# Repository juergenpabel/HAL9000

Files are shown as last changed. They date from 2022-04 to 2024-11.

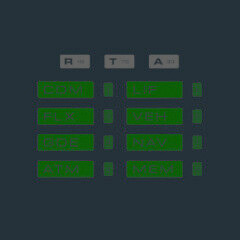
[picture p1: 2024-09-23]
enclosure/services/frontend/resources/images/animations/startup/system-starting/28.jpg

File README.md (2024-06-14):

# HAL9000
Open-source digital voice-assistant in a HAL9000 enclosure.

## Project goals
A digital voice-assistant that is...
1. actually usable (response times, error rates, ...)
2. performs everything on-device ("look ma, no cloud")
3. is entirely Free/Libre Open-Source-Software
4. is as-easy-as-possible to build

Not specifically a goal: price (although somewhat reasonable at 100-200€, depending on selection of components).

## Demos
Some showcase demo videos are published in the wiki: https://github.com/juergenpabel/HAL9000/wiki/Demos/

## Enclosure
The enclosure can be (mostly) 3D-printed, the STLs (generated with openscad, see resources/openscad/ in this repository) are on printables:
https://www.printables.com/model/218766-hal-9000

## Hardware
A bill-of-materials is available in this repository: https://github.com/juergenpabel/HAL9000/blob/master/resources/hardware/BOM.md

## Software
Is in this repository...except the installer, it is here: https://github.com/juergenpabel/HAL9000-installer

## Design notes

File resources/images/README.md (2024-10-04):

# Image sources

This project distributes images that are copied (and sometimes modified)
from other sources. Currently, images from two sources are used:
- Animations from the HAL9000 project, shown during system startup and shutdown
  - Source: https://github.com/armel/HAL9000/
  - Readme: [frontend/animations/README.md](frontend/animations/README.md)
- An animated HAL9000 (red) "eye", shown when interacting with the system by voice
  to indicate audio processing (aside from wake-word processing).
  - Source: http://www.jcheudin.fr/playground/playground/hal9000/
  - Readme: [frontend/animations/README.md](frontend/animations/README.md)

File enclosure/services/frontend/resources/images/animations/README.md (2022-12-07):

# HAL9000 startup and shutdown animations

The images used by this project are derived from source images,
which have been created by [Armel FAUVEAU](https://github.com/armel)
and were published under the MIT license. The MIT license is provided 
in this folder.

The animations provided here are based on:
- startup: [HAL 9000 Screensaver 4K \(16_9 Widescreen\) – COM \(Communications\) Animation 6 of 7.mp4](https://github.com/armel/HAL9000/tree/main/media/1440p/HAL%209000%20Screensaver%204K%20\(16_9%20Widescreen\)%20–%20COM%20\(Communications\)%20Animation%206%20of%207.mp4)
- shutdown: [HAL 9000 Screensaver 4K \(16_9 Widescreen\) – HIB \(Hibernation\) Animation 8 of 8.mp4](https://github.com/armel/HAL9000/tree/main/media/1440p/HAL%209000%20Screensaver%204K%20\(16_9%20Widescreen\)%20–%20HIB%20\(Hibernation\)%20Animation%208%20of%208.mp4)

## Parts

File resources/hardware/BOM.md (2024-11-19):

# Required hardware
- Raspberry Pi Zero2 (I am currently working on support for Orange Pi Zero 2W & Radxa Zero 3W)
- Respeaker 2-Mic HAT
- IDC/40pin extender cable 25-30cm
- 1.8" fisheye dome ([ebay.com](https://www.ebay.com/itm/301729022732)) # very hard to find/buy elsewhere
- 90° angled GPIO headers for Raspberry Pi
- Visaton K28.40 (previous versions used a K20.40 but that one is limited in terms of loudness)
- Wire mesh (90x50mm)
### Make or buy
- 3D printed: resources/openscad/hal9000-part*.scad (or STLs on [printables.com](https://www.printables.com/model/218766-hal-9000)) # Note: the display top frame and display cover exist in m5core2 and roundypi variants, print accordingly (everything else is "generic")
- CNC cutout: Black acryl faceplate 185x90x3mm with 50mm cutout (resources/openscad/acryl-faceplate.scad)

# Required hardware, dependant on build variant (choose one only, both work just as well)
### Variant m5stack Core2 (recommended, due to better availabily and ease of assembly)
- M5Stack Core2 **v1.1** ([m5stack.com](https://docs.m5stack.com/en/core/Core2%20v1.1)) (previous firmware versions implemented support for v1.0 but v1.1 is now more common)
- USB OTG cable Micro-USB->USB-C, 15-25cm with both connectors in 90° angle (for the Pi0: right-angled when looking from the Pi0)
- Cable: Grove->Qwiic/Stemma, 15-20cm (I couldn't find one with >10cm online, so I made on myself)
### Variant RoundyPI
- RoundyPI ([tindie.com](https://www.tindie.com/products/sbc/roundypi-128-round-lcd-based-on-rp2040-mcu/))
- USB OTG cable Micro-USB->Micro-USB, 15-25cm with one connector in 90° angle (for the Pi0: right-angled when looking from the Pi0)
- 6-pin 90° angled GPIO header
- Cable: Dupont(female)->Qwiic/Stemma, 15-20cm

# Optional hardware (only required if feature is desired)
### Feature: RFID Reader
- Adafruit MCP23017 GPIO expander (only one, can used also for rotary-encoder and motion sensor)
- RC522 I2C V1.1 ([ebay.com](https://www.ebay.de/itm/311768931452)) # easy to find/buy elsewhere, just make sure it is this specific version
### Feature: Rotary-Encoder
- Adafruit MCP23017 GPIO expander (only one, can used also for RFID reader and motion sensor)
- 2x 12mm Rotary Encoder (6mm shaft diameter) with button
### Feature: Motion sensor
- Adafruit MCP23017 GPIO expander (only one, can used also for RFID reader and rotary-encoder)
- 5.8GHz XYC-WB-DC motion sensor ([ebay.com](https://www.ebay.com/itm/255283290250)) # easy to find/buy elsewhere

# Other bits and pieces
- Various M2.5 standoffs and M2.5 + M3 screws
- A couple of dupont female cables, 10-20cm (partially one end has to be cut and soldered, like for onto the rotary encoders)
- 2x M3 flat nut plate ([ebay.com](https://www.ebay.com/itm/174105488144?var=472963777627)) # easy to find/buy elsewhere
- Flat Micro-USB power cable (for the Pi0: left-angled when looking from the Pi0)
### Optional (recommended for visual appearance or other reasons)
- Black 50mm diameter heat-shrink tube (for enclosing the ReSpeaker as a visual improvement to better hide the Respeaker behind the wire mesh)
- 4x 15x3mm neodym round magnets with screw sinks (for like magnetically "attaching" to a fridge or such)

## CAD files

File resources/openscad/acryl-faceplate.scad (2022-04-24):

$fn=360;


module acryl_faceplate() {
    difference() {
        square([+90.0,+185.0], center=true);
        translate([+00.0,-42.5]) circle(d=+50.0);
    }
}

acryl_faceplate();

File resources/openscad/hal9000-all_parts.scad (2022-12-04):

include <hal9000.scad>

conf_display = "m5core2"; // "roundypi";

conf_panel_rfid = true;
conf_panel_rotary = true;
conf_panel_motion = true;

translate([+00.0,+37.5,+00.0]) hal9000_enclosure_bottom();
translate([+00.0,+35.0,+00.0]) hal9000_enclosure_top();
translate([140.0,+12.5,+00.0]) hal9000_enclosure_panel();
translate([140.0,+12.5,+00.0]) hal9000_enclosure_panel_addons();
translate([+47.5,195.0,+00.0]) hal9000_component_display_frame_bottom();
translate([+47.5,115.0,+00.0]) hal9000_component_display_frame_top();
translate([140.0,180.0,+00.0]) hal9000_component_display_cover();
translate([140.0,115.0,+00.0]) hal9000_component_display_ring();

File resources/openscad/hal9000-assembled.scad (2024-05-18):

include <hal9000.scad>
// this rendering is best viewed if in openscad preview mode, because colors are shown

conf_display = "roundypi";

conf_panel_rfid = true;
conf_panel_rotary = true;
conf_panel_motion = true;

translate([+00.0,+00.0,+00.0]) rotate([+00,+00,+00]) hal9000_enclosure();
translate([+47.5,+18.5,235.0]) rotate([180,+00,+00]) hal9000_enclosure_panel();
translate([+47.5,+30.0,+97.5]) rotate([+90,+00,+00]) hal9000_component_display_frame_bottom();
translate([+47.5,+05.5,+97.5]) rotate([-90,+00,+00]) hal9000_component_display_frame_top();
translate([+47.5,+13.5,+97.5]) rotate([-90,+00,+00]) hal9000_component_display_cover();
translate([+47.5,+01.0,+97.5]) rotate([-90,+00,+00]) hal9000_component_display_ring();
translate([+47.5,+01.5,140.0]) rotate([-90,+00,+00]) hal9000_material_acryl();
translate([+47.5,+01.5,+97.5]) rotate([+90,+00,+00]) hal9000_material_fisheye();
translate([+47.5,+01.6,+25.0]) rotate([-90,+00,+00]) hal9000_material_wiremesh();

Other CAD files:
resources/openscad/hal9000-part_display-cover.scad
resources/openscad/hal9000-part_display-frame-bottom.scad
resources/openscad/hal9000-part_display-frame-top.scad
resources/openscad/hal9000-part_display-ring.scad
resources/openscad/hal9000-part_enclosure-bottom.scad
resources/openscad/hal9000-part_enclosure-panel.scad
resources/openscad/hal9000-part_enclosure-panel_addons.scad
resources/openscad/hal9000-part_enclosure-top.scad
resources/openscad/hal9000.scad

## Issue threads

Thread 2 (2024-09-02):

arduino firmware: random crashes/freezes on RP2040 when running MCP23X17 task on 2nd core

juergenpabel, 2024-09-02:
The arduino firmware crashes/freezes randomly (only) when run on RP2040 with the MCP23X17 running as a task on the 2nd core (works without issues on ESP32). I have already analyzed for potential causes but didn't come up with a reasonable explanation, so for now I am assuming some issue in the [arduino-pico](https://github.com/earlephilhower/arduino-pico/) runtime; until I can identify the cause this issue is meant to document the process (and if it does indeed turn out to be an issue in arduino-pico, I will open an issue there and link here).

As a workaround I disabled task creation for RP2040 firmwares (see `Microcontroller::task_create()` in enclosure/firmware/arduino/src/device/microcontroller/rp2040.cpp) and regular checking of MCP23X17 states is invoked from `loop()`).

juergenpabel, 2024-09-13:
OK, so the issue seems to be that (for RP2040 only):
- 1) I had only implemented recursive mutexes
- 2) the owner id of recursive mutexes (which should be the cpu core of the given execution context) doesn't seem be set and/or validated correctly (I haven't investigated further)

So a working workaround is (for RP2040) to switch over to (non-recursive) mutex - due to code changes recursiveness isn't relevant anymore anyhow, so I might just remove recursiveness alltogether.

juergenpabel, 2024-09-13:
support for recursive mutexes removed

juergenpabel, 2024-09-14:
Reopened as crashes/freezes still occur...randomly

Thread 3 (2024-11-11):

New LCD 1.28" hardware alternative

joaomorenorf, 2024-11-11:
Hello, thank you for your great work!

I started buying the pieces and noticed a [cheaper option for the LCD](https://www.aliexpress.com/item/1005005845152306.html). To use it, I need to modify the reSpeaker board and add some code to the Raspberry, but it might work.

The idea is to remove the LEDs from reSpeaker, freeing Raspberry Pi's SPI0. With the SPI0 free, we could use it to drive the LCD.

| reSpeaker | Raspberry |
|---|---|
| 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 | 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|

Can you help me adapt the code to work this way?

Thank you in advance

juergenpabel, 2024-11-12:
Hi, I also did think about not using a microcontroller for the display but because there's also the task of handling input (rotaries, buttons, etc) I decided to go with micrcontrollers for all input+output purpose (with the exception of audio). As my codebase evolved and matured over time, I think it should now be fairly simple (and project architecture "compliant") to implement a "driver" for a RPi-attached display (SPI or other): it would be another "frontend"-backend, just like the currently implemented backends "arduino" (talk to arduino via USB) and "flet" (present display as webpage). Checkout out `enclosure/services/frontend/package/hal9000/frontend/flet/hal9000.py` (that's the whole "flet" backend) to get an idea of what kind of functionality (different screens) needs to be implemented on top of the display driver.

Let me know what type of display you're going to use (or are considering) and I'll get one myself to help with the implementation.

Last question (for now): You're building it without hardware inputs (rotaries/buttons/...)?

juergenpabel, 2024-11-12:
One more thought: There's no real need to use a round display, the display cover (in which the dome is set) has a round cutout - so a regular (non-round) display will work just the same. I suspect those might be even cheaper and/or easier to find.

juergenpabel, 2024-11-12:
One more thought: There's no real need to use a round display, the display cover (in which the dome is set) has a round cutout - so a regular (non-round) display will work just the same. I suspect those might be even cheaper and/or easier to find.

joaomorenorf, 2024-11-14:
Hey @juergenpabel,

I'll look into the file you pointed out, thank you.

I'm planning on using this screen: https://www.aliexpress.com/item/1005007097538439.html

I'll not add rotaries or buttons

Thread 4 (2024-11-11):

Add disassembled pictures to help build the device

joaomorenorf, 2024-11-11:
Hello,

Can you add more pictures of the device disassembled?

I want to be sure of how to wire things up.

Thank you!

juergenpabel, 2024-11-12:
I have plenty of pictures, I'll post some (in this issue as a first step) within the next few days. I am planning on writing assembly documentation and making an assembly video within the next weeks.

turaluralu, 2025-04-28:
Hi,
wanted to make this cool device but can´t find a circuit diagram. Are there meanwhile some Pictures to see how to assemble the components?

juergenpabel, 2025-05-04:
Hi @turaluralu (and @joaomorenorf),

I had to put HAL aside for a while due to work priorities - I hope to get back to this project in the next couple of weeks.

@turaluralu: I found a basic wiring overview in one of my presentations - does that help?:
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

@joaomorenorf: Here are some (rather random) assembly pictures (including an optional motion sensor, the XYC-WB-DC):

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

turaluralu, 2025-05-04:
Hi,
thanks for the pictures and the circuit diagramm. That helps I think :-) I hope that you´ll find time in the future for this great project.

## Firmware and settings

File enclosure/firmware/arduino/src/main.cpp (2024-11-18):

#include <FS.h>
#include <LittleFS.h>
#include <TimeLib.h>

#include "globals.h"
#include "device/webserial.h"
#include "system/webserial.h"
#include "peripherals/webserial.h"
#include "gui/gui.h"
#include "gui/screen/screen.h"
#include "gui/screen/error/screen.h"
#include "gui/screen/idle/screen.h"
#include "gui/screen/splash/screen.h"
#include "gui/screen/animations/screen.h"
#include "gui/overlay/overlay.h"
#include "gui/webserial.h"
#include "util/webserial.h"
#include "util/jpeg.h"


void setup() {
	static StaticJsonDocument<APPLICATION_JSON_FILESIZE_MAX*2>  json;
	static etl::string<GLOBAL_VALUE_SIZE>                       error_details;
	static etl::string<GLOBAL_FILENAME_SIZE>                    filename;
	       File                                                 file;

	if(g_device_board.start() == false) { //TODO: what to do??
		g_system_application.setRunlevel(RunlevelPanicing); //TODO: what to do??
		return;
	}
	g_gui.begin();
	g_gui.setRotation(TFT_ORIENTATION_LOGICAL);
	g_gui.fillScreen(TFT_BLACK);
	g_gui_buffer.setColorDepth(16);
	g_gui_buffer.createSprite(GUI_SCREEN_WIDTH, GUI_SCREEN_HEIGHT);
	if(g_gui_buffer.getPointer() == nullptr) {
		g_util_webserial.send("syslog/warning", "out-of-memory: UI running without frame buffer (reduced graphics)");
	}
	filename  = "/device/board/";
	filename += g_device_board.getIdentifier();
	filename += ".json";
	if(LittleFS.exists(filename.c_str()) == false) {
		error_details  = "board configuration file (littlefs:)'";
		error_details += filename;
		error_details += "' not found";
		g_system_application.processError("panic", "213", "Board error", error_details);
		return;
	}
	file = LittleFS.open(filename.c_str(), "r");
	if(static_cast<bool>(file) == false) {
		error_details  = "failed to open *supposedly existing* (littlefs:)'";
		error_details += filename;
		error_details += "' in read-mode";
		g_system_application.processError("panic", "212", "Filesystem error", error_details);
		return;
	}
	if(deserializeJson(json, file) != DeserializationError::Ok) {
		error_details  = "JSON (syntax) error in board configuration in (littlefs:)'";
		error_details += filename;
		error_details += "'";
		g_system_application.processError("panic", "213", "Board error", error_details);
		file.close();
		return;
	}
	file.close();
	if(g_device_board.configure(json) == false) {
		error_details  = "board '";
		error_details += g_device_board.getIdentifier();
		error_details += "' reported an error applying config from (littlefs:)'";
		error_details += filename;
		error_details += "'";
		g_system_application.processError("panic", "213", "Board error", error_details);
		return;
	}
	g_util_webserial.addCommand("system/runlevel", on_system_runlevel);
	gui_screen_set("animations:system-starting", gui_screen_animations);
}


void loop() {
	static Runlevel  previousRunlevel = RunlevelStarting;
	       Runlevel  currentRunlevel;

	currentRunlevel = g_system_application.getRunlevel();
	if(currentRunlevel != previousRunlevel) {
		g_util_webserial.send("system/runlevel", g_system_application.getRunlevelName());
		switch(currentRunlevel) {
			case RunlevelConfiguring:
				if(g_system_application.loadSettings("/system/settings.ini") == false) {
					g_system_application.processError("panic", "214", "Application error", "system failed to load persisted settings " \
					                                                                       "from (littlefs:)'/system/settings.ini' " \
					                                                                       "(reflashing littlefs might solve this issue..." \
					                                                                       "but not the root cause)");
					return;
				}
				g_util_webserial.addCommand("system/environment", on_system_environment);
				g_util_webserial.addCommand("system/settings", on_system_settings);
				g_util_webserial.addCommand("system/features", on_system_features);
				g_util_webserial.addCommand("device/microcontroller", on_device_microcontroller);
				g_util_webserial.addCommand("device/board", on_device_board);
				g_util_webserial.addCommand("device/display", on_device_display);
				g_util_webserial.addCommand("peripherals/mcp23X17", on_peripherals_mcp23X17);
				gui_screen_set("animations:system-configuring", gui_screen_animations);
				break;
			case RunlevelRunning:
				g_util_webserial.delCommand("device/microcontroller", on_device_microcontroller);
				g_util_webserial.delCommand("device/board", on_device_board);
				g_util_webserial.delCommand("device/display", on_device_display);
				g_util_webserial.delCommand("peripherals/mcp23X17", on_peripherals_mcp23X17);
				g_util_webserial.addCommand("gui/screen", on_gui_screen);
				g_util_webserial.addCommand("gui/overlay", on_gui_overlay);
				break;
			case RunlevelRestarting:
				g_util_webserial.clearCommands();
				g_util_webserial.addCommand("system/runlevel", on_system_runlevel);
				g_util_webserial.addCommand("system/environment", on_system_environment);
				gui_screen_set("animations:system-terminating", gui_screen_animations); //animation triggers reset after last frame
				break;
			case RunlevelHalting:
				g_util_webserial.clearCommands();
				g_util_webserial.addCommand("system/runlevel", on_system_runlevel);
				g_util_webserial.addCommand("system/environment", on_system_environment);
				gui_screen_set("animations:system-terminating", gui_screen_animations); //animation triggers halt after last frame
				break;
			case RunlevelPanicing:
				g_util_webserial.clearCommands();
				g_util_webserial.addCommand("system/runlevel", on_system_runlevel);
				break;
			default:
				g_system_application.processError("panic", "219", "Application error", "Unknown system runlevel (BUG!), panicing");
		}
		previousRunlevel = currentRunlevel;
	}
	if(currentRunlevel == RunlevelRunning) {
		g_peripherals_mcp23X17.check(false);
	}
	g_util_webserial.update();
	gui_update();
}

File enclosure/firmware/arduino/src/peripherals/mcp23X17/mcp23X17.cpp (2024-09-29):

#include <Adafruit_MCP23X17.h>
#include <ArduinoJson.h>
#include <etl/format_spec.h>
#include <etl/to_string.h>

#include "gui/overlay/overlay.h"
#include "peripherals/mcp23X17/devices.h"
#include "peripherals/mcp23X17/mcp23X17.h"
#include "globals.h"

static MCP23X17_Switch      g_devices_switch[2];
static MCP23X17_Button      g_devices_button[2];
static MCP23X17_Rotary      g_devices_rotary[2];
static MCP23X17_DigitalOut  g_devices_digitalout[2];

etl::string<2> MCP23X17::PIN_NAMES[16] = {"A0","A1","A2","A3","A4","A5","A6","A7","B0","B1","B2","B3","B4","B5","B6","B7"};
etl::string<4> MCP23X17::PIN_VALUES[2] = {MCP23X17_PIN_VALUE_LOW, MCP23X17_PIN_VALUE_HIGH};

#define MCP23X17_STATE_UNINITIALIZED 0x10
#define MCP23X17_STATE_INITIALIZED   0x20
#define MCP23X17_STATE_RUNNING       0x30
#define MCP23X17_STATE_RUNNING_MAIN  0x31
#define MCP23X17_STATE_RUNNING_TASK  0x32

 
MCP23X17::MCP23X17()
         :status(MCP23X17_STATE_UNINITIALIZED),
          mcp23X17() {
}


bool MCP23X17::init() {
	int i2c_bus     = 0;
	int i2c_address = 0x20;

	if(g_system_application.hasSetting("peripherals/mcp23X17:i2c/bus") == true) {
		i2c_bus = atoi(g_system_application.getSetting("peripherals/mcp23X17:i2c/bus").c_str());
	}
	if(g_system_application.hasSetting("peripherals/mcp23X17:i2c/address") == true) {
		i2c_address = atoi(g_system_application.getSetting("peripherals/mcp23X17:i2c/address").c_str());
	}
	return this->init(i2c_bus, i2c_address);
}


bool MCP23X17::init(uint8_t i2c_bus, uint8_t i2c_addr) {
	TwoWire* twowire = nullptr;

	if(this->status != MCP23X17_STATE_UNINITIALIZED) {
		g_system_application.addErrorContext("MCP23X17 already initialized");
		return false;
	}
	twowire = g_device_microcontroller.twowire_get(i2c_bus);
	if(twowire == nullptr) {
		g_system_application.addErrorContext("failed to obtain TwoWire instance for I2C communications with MCP23X17");
		return false;
	}
	if(this->mcp23X17.begin_I2C(i2c_addr, twowire) == false) {
		g_system_application.addErrorContext("failed to initiate I2C communications with MCP23X17");
		return false;
	}
	this->status = MCP23X17_STATE_INITIALIZED;
	return true;
}


bool MCP23X17::config_inputs(const etl::string<GLOBAL_KEY_SIZE>& device_type, const etl::string<GLOBAL_KEY_SIZE>& device_name, const JsonArray& inputs, const JsonObject& events) {
	MCP23X17_InputDevice* device = nullptr;

	if(this->status == MCP23X17_STATE_UNINITIALIZED) {
		this->init();
	}
	if((this->status & MCP23X17_STATE_RUNNING) == MCP23X17_STATE_RUNNING) {
		g_system_application.addErrorContext("MCP23X17 already started, configuration of inputs not possible any more");
		return false;
	}
	if(device_type.size() == 0 || device_name.size() == 0) {
		g_system_application.addErrorContext("MCP23X17::config_inputs(): invalid parameters name/type");
		return false;
	}
	if(device_type.compare("switch") == 0) {
		for(int i=0;i<3;i++) {
			if(device == nullptr && g_devices_switch[i].isConfigured() == false) {
				device = &g_devices_switch[i];
			}
		}
	}
	if(device_type.compare("button") == 0) {
		for(int i=0;i<3;i++) {
			if(device == nullptr && g_devices_button[i].isConfigured() == false) {
				device = &g_devices_button[i];
			}
		}
	}
	if(device_type.compare("rotary") == 0) {
		for(int i=0;i<3;i++) {
			if(device == nullptr && g_devices_rotary[i].isConfigured() == false) {
				device = &g_devices_rotary[i];
			}
		}
	}
	if(device == nullptr) {
		g_system_application.addErrorContext("MCP23X17::config_inputs(): invalid value for parameter 'device_type'");
		return false;
	}
	if(device->configure(device_name, &this->mcp23X17, inputs, events) == false) {
		g_system_application.addErrorContext("MCP23X17::config_inputs(): device configuration failed");
		return false;
	}
	return true;
}


bool MCP23X17::config_outputs(const etl::string<GLOBAL_KEY_SIZE>& device_type, const etl::string<GLOBAL_KEY_SIZE>& device_name, const JsonArray& outputs) {
	MCP23X17_OutputDevice* device = nullptr;

	if(this->status == MCP23X17_STATE_UNINITIALIZED) {
		this->init();
	}
	if((this->status & MCP23X17_STATE_RUNNING) == MCP23X17_STATE_RUNNING) {
		g_system_application.addErrorContext("MCP23X17 already started, configuration of outputs not possible any more");
		return false;
	}
	if(device_type.size() == 0 || device_name.size() == 0) {
		g_system_application.addErrorContext("MCP23X17::config_outputs(): invalid parameters name/type");
		return false;
	}
	if(device_type.compare("digital") == 0) {
		for(int i=0;i<3;i++) {
			if(device == nullptr && g_devices_digitalout[i].isConfigured() == false) {
				device = &g_devices_digitalout[i];
			}
		}
	}
	if(device == nullptr) {
		g_system_application.addErrorContext("MCP23X17::config_outputs(): invalid value for parameter 'device_type'");
		return false;
	}
	if(device->configure(device_name, &this->mcp23X17, outputs) == false) {
		g_system_application.addErrorContext("MCP23X17::config_outputs(): device configuration failed");
		return false;
	}
	return true;
}


bool MCP23X17::start(bool run_as_task) {
	bool result = false;

	if(this->status != MCP23X17_STATE_INITIALIZED) {
		g_system_application.addErrorContext("MCP23X17::start(): called with invalid state (BUG)");
		return false;
	}
	g_device_microcontroller.mutex_enter("gpio");
	this->mcp23X17_gpio_values = this->mcp23X17.readGPIOAB();
	g_device_microcontroller.mutex_leave("gpio");
	switch(run_as_task) {
		case true:
			result = g_device_microcontroller.task_create("MCP23X17", MCP23X17::loop, 1);
			if(result == true) {
				g_util_webserial.send("syslog/debug", "MCP23X17::loop() started on 2nd core");
				this->status = MCP23X17_STATE_RUNNING_TASK;
			} else {
				g_util_webserial.send("syslog/warn", "MCP23X17::loop() failed to start task on 2nd core, falling back to invocations from loop()");
				this->status = MCP23X17_STATE_RUNNING_MAIN;
				result = true;
			}
			break;
		case false:
			this->status = MCP23X17_STATE_RUNNING_MAIN;
			result = true;
			break;
	}
	return result;
}
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

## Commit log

2022-04-21 install script for raspberry-os:bullseye
2022-04-24 enclosure now working in uwsgi
2022-04-24 added openscad files for STL generation
    [acryl-faceplate.scad, hal9000-all_parts.scad, hal9000-assembled.scad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]
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2022-04-24 minor changes in openscad files
    [hal9000-all_parts.scad, hal9000-part_enclosure-panel.scad, hal9000-part_enclosure-top.scad]
2022-04-25 openscad cleanup
    [hal9000-all_parts.scad, hal9000-part_enclosure-panel.scad, hal9000-part_rfid-cover.scad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]
2022-04-25 working uwsgi:kalliope for en-us
    [computer-en.pb.params]
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2022-05-05 added driver for rotary encoders attached to mcp230xx
2022-05-09 mcp230xx added interrupt logic
2022-05-20 file reorg for enclosure/src/display/...
2022-05-20 [WIP] initial mfrc522_i2c based driver implementation
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2022-05-24 major class refactoring in enclosure/src
2022-05-24 more refactoring in enclosure/src
2022-05-24 major class refactoring in enclosure/src/peripherals
2022-05-25 worked on driver for pcf8591
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2022-05-28 WIP in enclosure/src for 'brain' daemon
2022-05-30 more work on brain daemon in enclosure/src
2022-05-31 WIP refactoring/cleanup in enclosure/src
2022-06-10 more 'brain work' ;) in enclosure
2022-06-12 enclosure: button -> switch and added config options for invert and debounce
2022-06-21 BMPs and openscad
    [hal9000-all_parts.scad, hal9000-assembled.scad, hal9000-part_enclosure-panel.scad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]
2022-06-24 firmware for roundypi as another display device
    [hal9000-part_enclosure-panel.scad, hal9000-part_enclosure-panel_addons.scad, hal9000.scad]
2022-07-03 enclosure firmware for roundypi: added time sync
2022-07-06 enclosure: roundypi firmware WIP
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2022-07-09 enclosure: roundypi refactoring WIP
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2022-07-29 enclosure: roundypi rotary encoder events
2022-08-10 arduino firmware and daemons WIP
2022-08-13 added html frontend for testing without hardware
    [hal9000-assembled.scad]
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2022-08-18 enclosure: brain and firmware functional
2022-08-24 enclosure daemons refactoring, WIP
2022-08-24 enclosure: brain daemon refactoring enclosure plugin, WIP
2022-08-24 enclosure brain daemon refactoring, WIP
2022-08-25 enclosure: brain daemon + firmware menu implementation, WIP
2022-08-27 enclosure: brain daemon added menu logic
2022-08-29 enclosure: brain+arduino refined menu implementation
2022-08-31 enclosure: firmware refactoring and state of conciousness implemented
2022-08-31 enclosure: firmware minor improvements
2022-08-31 enclosure: firmware renamed Status to Runtime
2022-08-31 enclosure: firmware renamed Status to Runtime (missing change)
2022-09-02 enclosure: firmware and daemons, various changes
2022-09-02 enclosure: firmware and daemons, awake+asleep states now working
2022-09-02 enclosure: daemon startup process simplified and remove peripherals+display daemons (old hardware)
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2022-09-06 firmware: recover time after reset from rp2040 scratch register
    [rp2040.cpp]
2022-09-11 daemons/arduino: reworked webserial handling
2022-09-14 firmware: migrated to ETL and replaced SimpleWebSerial library with own implementation
    [devices.cpp, main.cpp, mcp23X17.cpp]
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2022-09-20 firmware: fixed compile errors
    [webserial.cpp]
2022-10-07 3D model option for m5stack-core2
    [hal9000-all_parts.scad, hal9000-assembled.scad, hal9000-part_display-cover.scad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]
2022-10-08 firmware: added board abstraction
    [default_16MB.csv]
2022-10-11 [wip] firmware: initial m5stack-core2 implementation
    [default_16MB.csv, partitions.csv]
2022-10-12 openscad: minor changes
    [hal9000-all_parts.scad, hal9000-assembled.scad, hal9000-part_display-frame-top.scad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]
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2022-10-13 openscad: reduced display hole for m5stack-core
    [hal9000.scad]
2022-12-01 enclosure: moved from visaton K20.40 to K28.40 speaker due to much better quality
    [hal9000.scad]
2022-12-04 STL: changed default to m5stack-core2
    [hal9000-all_parts.scad]
2022-12-09 firmware+daemons: added a heartbeat/ping functionality to detect unresponsive arduino; also some more WIP
2023-01-14 firmware: started implementing new error handling
    [esp32.cpp]
2023-01-15 firmware: continued implementing new error handling
    [main.cpp]
2023-01-21 firmware: finished implementing new error handling
    [main.cpp, mcp23X17.h, webserial.cpp]
2023-01-30 major file reorganisation
    [computer-en.pb.params, partitions.csv]
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2023-02-13 daemon: adding system-{console|database|agent}
    [computer-en.pb.params]
2024-05-18 reverting back to commit when branch 'refactoring' was created (for merging it next)
    [computer-en.pb.params, partitions.csv]
2024-05-18 merged branch 'refactoring'
    [computer-en.pb.params, hal9000-assembled.scad, hal9000.scad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]
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2024-05-30 frontend: added check for non-matching arduino during mcp23X17 configuration
2024-06-01 adapted brain and frontend:flet to (some time ago) changed topic scheme from arduino implementation
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2024-06-05 brain: changed name of thread for mqtt handling
2024-06-08 updated demo-en_US in kalliope because of changed ALSA device ('plughw:HAL9000' instead of 'hw:HAL9000' due to framerate issues on some systems)
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2024-06-17 firmware: added a qrcode screen (and make error screen use that)
    [webserial.cpp]
2024-06-18 replaced non-yet-implemented 'settings' menu in UI with 'services' (showing URLs for HTML console+frontend)
    [main.cpp]
2024-06-19 brain: added lookup of host ip-address using (mounted) system dbus in container (currently hacky as dbus-fast uses async/await which brain does not (yet) use
2024-07-08 frontent:flet: added sleep+wakeup buttons, corrected flet page scaling logic, implemented time unsynced indicator (red font) and even more (minor things)...
2024-07-10 firmware+brain+frontend: reworked NTP sync logic, adding a splash screen for brain when 'ready' (will wait for NTP sync before changing to awake or asleep)
    [main.cpp, webserial.cpp]
2024-07-16 firmware/arduino: replaced screen 'hal9000' with 'animations', changed startup logic and animations; brain+kalliope: split up 'status' into 'runlevel' and 'status', adapted code as per firmware chang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
    [esp32.cpp, main.cpp, webserial.cpp]
2024-07-16 firmware/arduino: reduced images (quality and frames) for 1.75MB littlefs target-size
    [partitions.csv]
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2024-07-16 resources: removed animations/startup/system-starting/15.jpg (duplicate frame) for at least some littlefs free space
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2024-07-25 frontend: fixed ESP32 crash on MCP23X17 task (SPI+I2C lock), changed startup animations and some minor code changes
    [board.cpp, esp32.cpp, mcp23X17.cpp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]
2024-07-25 arduino: tuned delay settings for loop() and mcp23X17 task for improved rotaries+buttons interactions
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2024-08-14 brain: reworked internal item state handling ; firmware: adapted event reporting to host to match brain triggers ; frontend: added config option to load application config from littlefs
    [devices.cpp, main.cpp, mcp23X17.cpp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]
2024-08-20 firmware: reworked webserial queueing
    [esp32.cpp, main.cpp, mcp23X17.cpp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]
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2024-08-29 firmware: reworked gui update logic
    [main.cpp, mcp23X17.cpp, webserial.cpp]
2024-08-30 brain+firmware: added screen parameter to some screens (error,splash,animations) for improved logging
    [main.cpp, webserial.cpp]
2024-09-03 brain,frontend,firmware: improved service (re-)start handling / firmware: workaround for rp2040 concurrency issue (see github issue #2)
    [main.cpp, mcp23X17.cpp, mcp23X17.h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]
2024-09-03 firmware: reworked shutdown (reboot/halt) animation logic and images
    [board.cpp, main.cpp, webserial.cpp]
2024-09-12 reworked error handling/messaging and included panicing state for arduino
    [board.cpp, devices.cpp, esp32.cpp]
2024-09-13 #2 fixed rp2040 mutex issue and removed support for recursive mutexes
    [board.cpp, esp32.cpp, rp2040.cpp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]
2024-09-14 firmware: change to error:210 screen in WebSerial::update only when application status is waiting or running
    [webserial.cpp]
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2024-09-15 firmware: always show error:210 screen if serial connection is lost (in app states waiting+running)
    [webserial.cpp]
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2024-09-26 changed arduino poweroff/reboot command
    [webserial.cpp]
2024-09-27 firmware: reworked gui internals and error handling
    [board.cpp, devices.cpp, esp32.cpp]
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2024-10-18 brain+frontend[flet]+firmware: changed display power-on/off invocation from gui/screen 'on'/'off' to system/features 'display.backlight'
2024-10-24 brain: removed switching to 'none' screen for sleep'ing
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2024-11-09 brain: rewrote .../plugin/enclosure/control.py [WIP] and added plugin 'http'
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2024-11-18 firmware: support for m5stack-core2 V1.1 (instead of V1.0) / frontend+firmware: removed littlefs backed arduino configuration / frontend: renamed animations to match runlevels
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
